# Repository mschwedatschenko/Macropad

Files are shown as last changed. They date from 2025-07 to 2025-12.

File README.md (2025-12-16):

# 3x3 Macropad Custom PCB 
This PCB was designed in KiCad and programmed in Arduino IDE using C++. I used OSHPark as my manufacturer of choice, and got some beautiful purple PCBs with ENIG surface finish. The Macropad acts as a HID, with each key representing a number 1-9. These keys can be programmed to be anything the user wants.

## Pictures

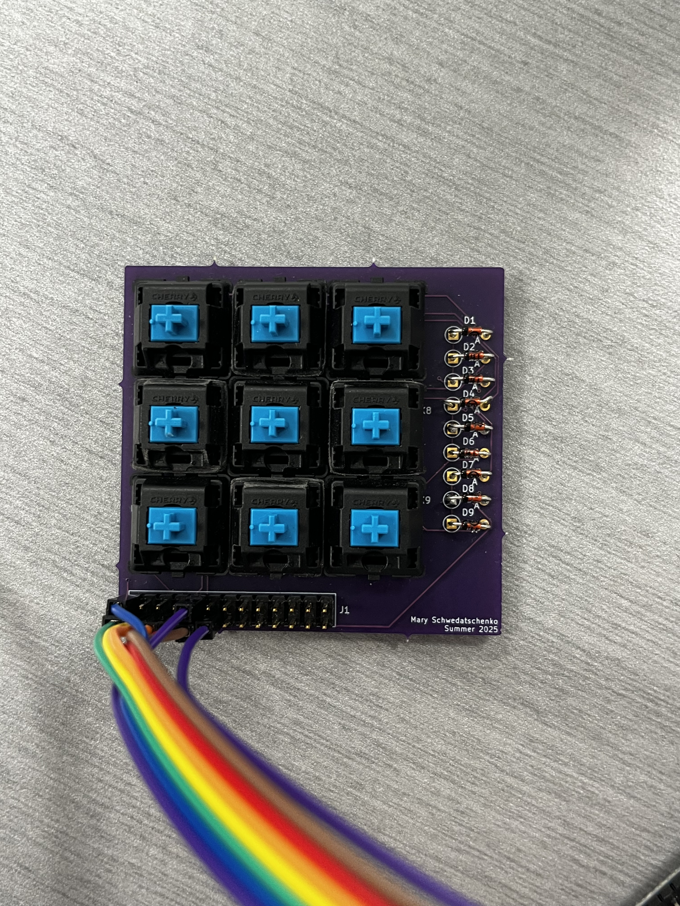
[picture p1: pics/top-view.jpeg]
board image


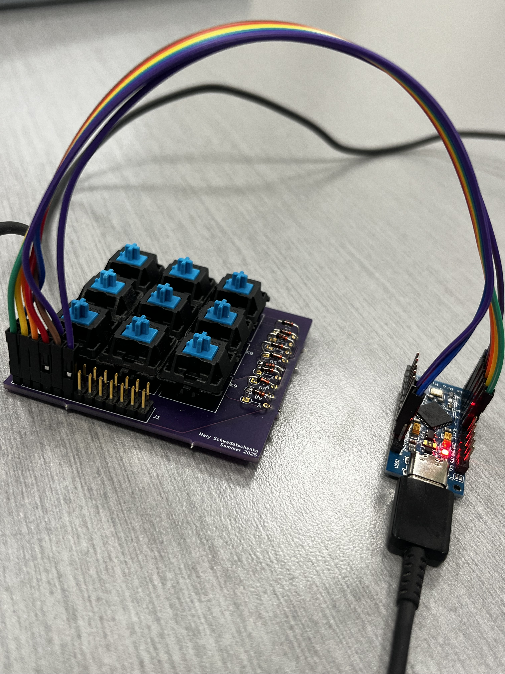
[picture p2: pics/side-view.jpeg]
board side


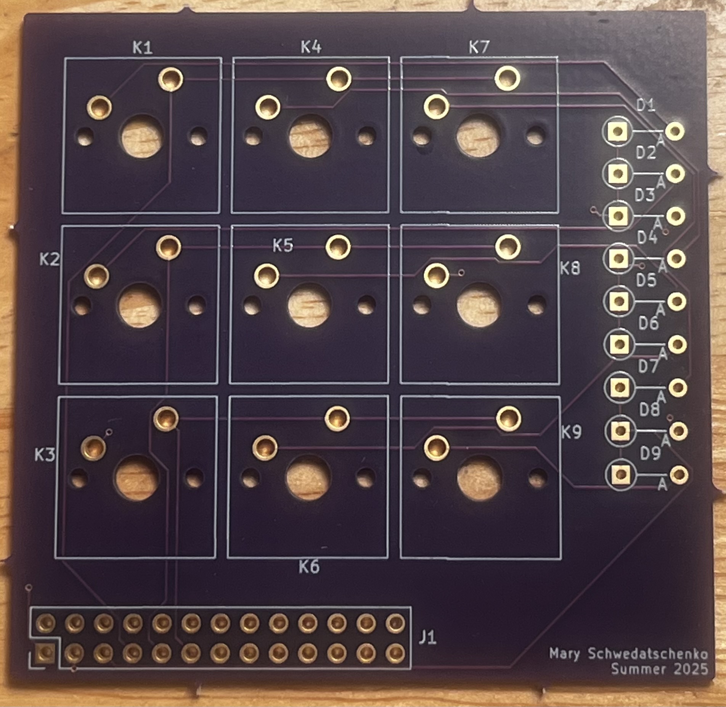
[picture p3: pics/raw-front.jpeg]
raw board front


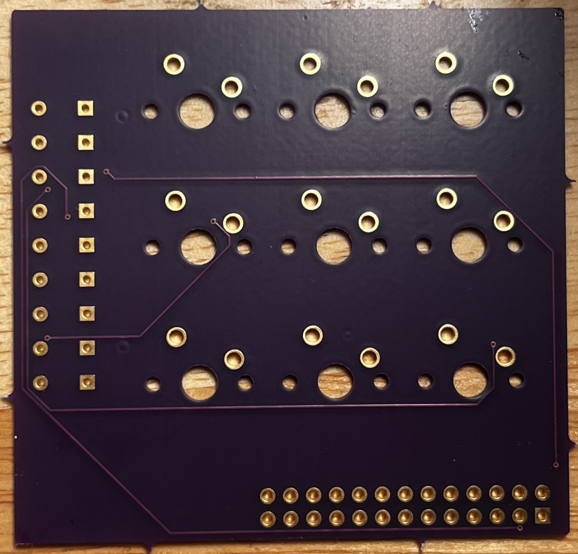
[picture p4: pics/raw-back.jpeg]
raw board back


Here's the schematic of my design:

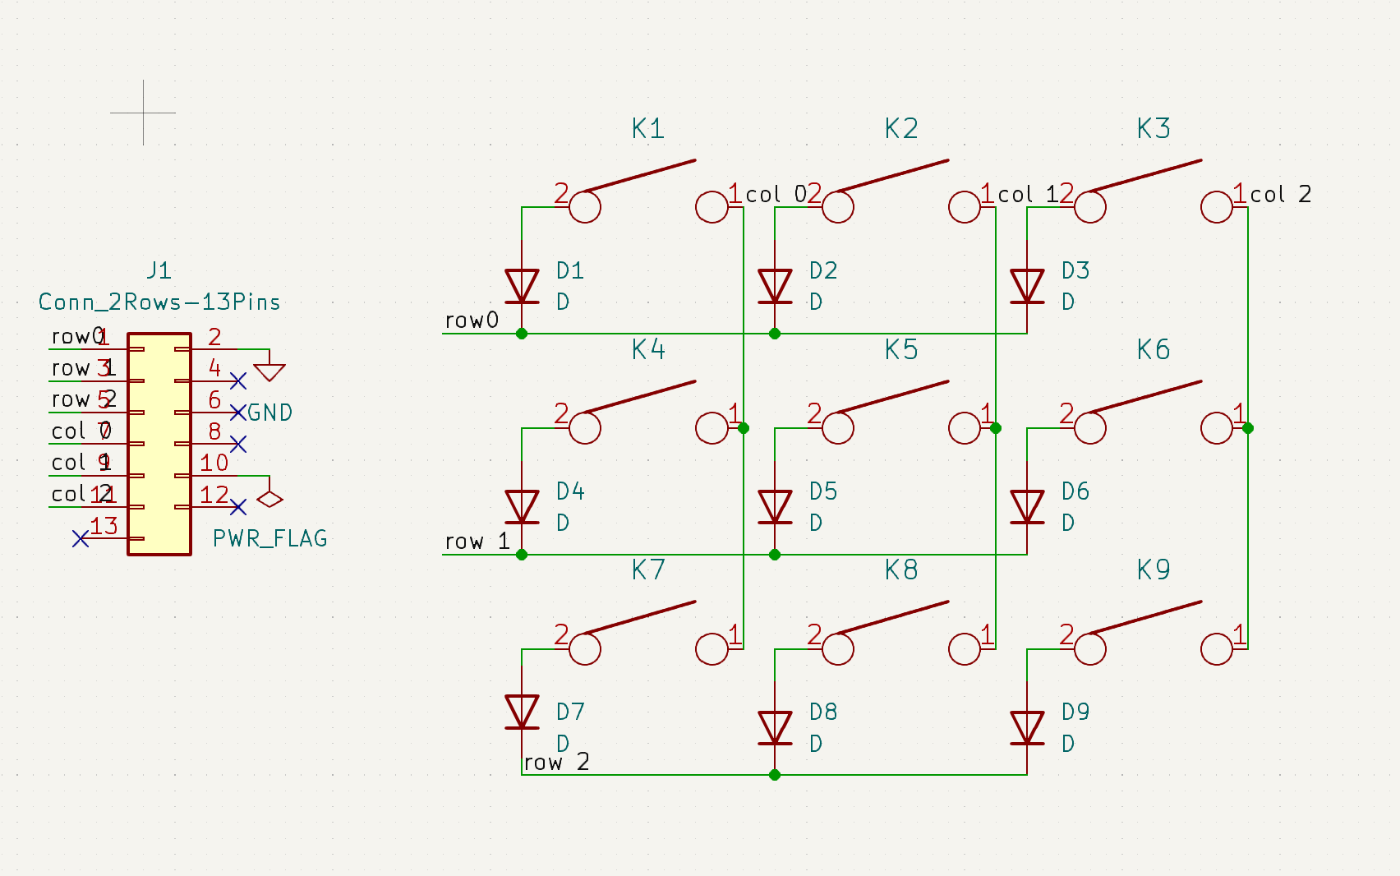
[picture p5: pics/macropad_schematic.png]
schematic


Here's the PCB layout of my design:

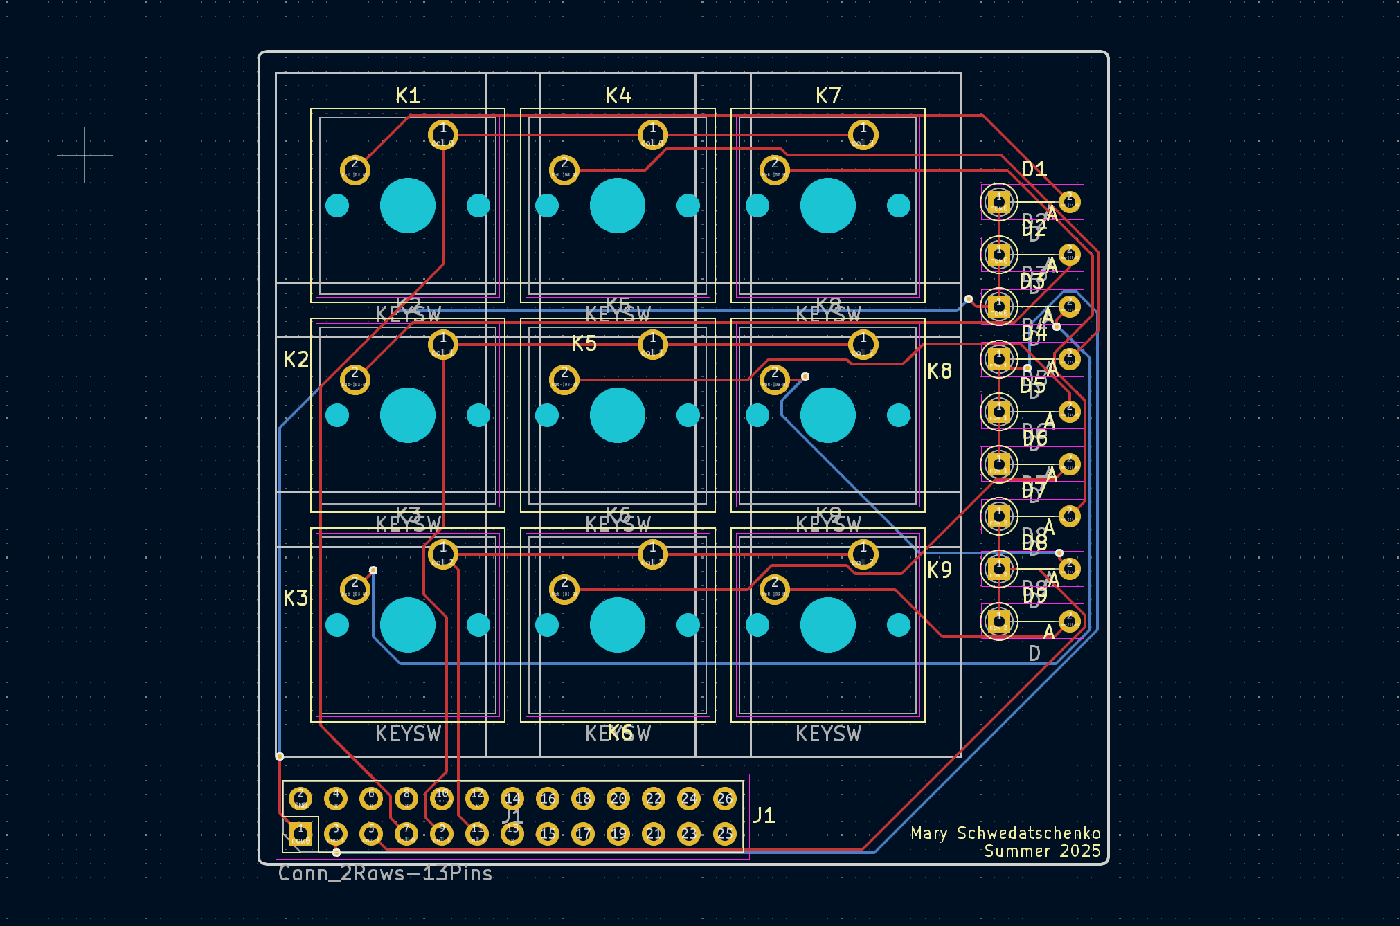
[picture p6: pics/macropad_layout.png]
layout


## Notes
I made the switch footprints far too close to one another, so I had to sand down the switches in order for them to be soldered correctly. This design does not support keycaps. Additionally, future iterations should include the Arduino Micro on the board itself, as it is a pain to have the Arduino Micro hanging off.

I'm currently in the process of making a 60% Keyboard PCB. 

## Purpose
After losing access to my mechanical keyboard I used for a while and just relying on my laptop's built-in keyboard, I had the desire to make my own mechanical keyboard completely from scratch. This macropad serves as a precursor to a 60% keyboard I hope to create during this academic year using a bare ATMega32U4 Microcontroller rather than an Arduino Micro, and to test the waters with the project on a smaller scale. 

It made sense to stick with the Arduino Micro for the microcontroller for this project since I will be strictly using through-hole soldering. With the 60% project, having regular access to WPI's reflow oven will yield hopefully better results using SMT soldering (hand soldering all of the pins on the microcontroller sounds like a nightmare).

I hope to make the switches on the 60% keyboard hot-swappable. I used Cherry MX switches for this macropad and soldered them directly to the PCB.

## BOM
Arduino Micro (alternative knockoff linked here)
https://www.amazon.com/dp/B0B6HYLC44?ref=ppx_yo2ov_dt_b_fed_asin_title 

9x THT Diodes
https://www.digikey.com/en/products/detail/onsemi/1N4148/458603 

9x Cherry MX Switches
https://www.digikey.com/en/products/detail/cherry-americas-llc/MX1A-E1NW/20180

1x 2x12 Pin Header
https://www.mouser.com/ProductDetail/Amphenol-FCI/67996-126HLF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 

Female to Female Jumper Wires
https://www.amazon.com/California-JOS-Breadboard-Optional-Multicolored/dp/B0BRTKTV64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

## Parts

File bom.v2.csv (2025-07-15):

Reference | Value | Datasheet | Footprint | Qty | DNP
D1,D2,D3,D4,D5,D6,D7,D8,D9 | D | ~ | Diode_THT:D_DO-35_SOD27_P5.08mm_Vertical_AnodeUp | 9
J1 | Conn_2Rows-13Pins | ~ | Connector_PinHeader_2.54mm:PinHeader_2x13_P2.54mm_Vertical | 1
K1,K2,K3,K4,K5,K6,K7,K8,K9 | KEYSW |  | Button_Switch_Keyboard:SW_Cherry_MX_1.00u_PCB | 9

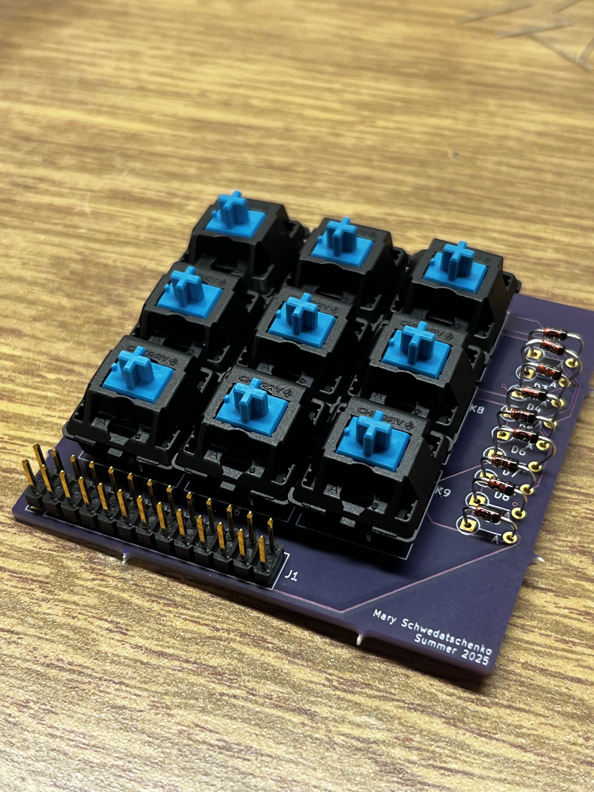
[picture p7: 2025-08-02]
pics/components.jpeg

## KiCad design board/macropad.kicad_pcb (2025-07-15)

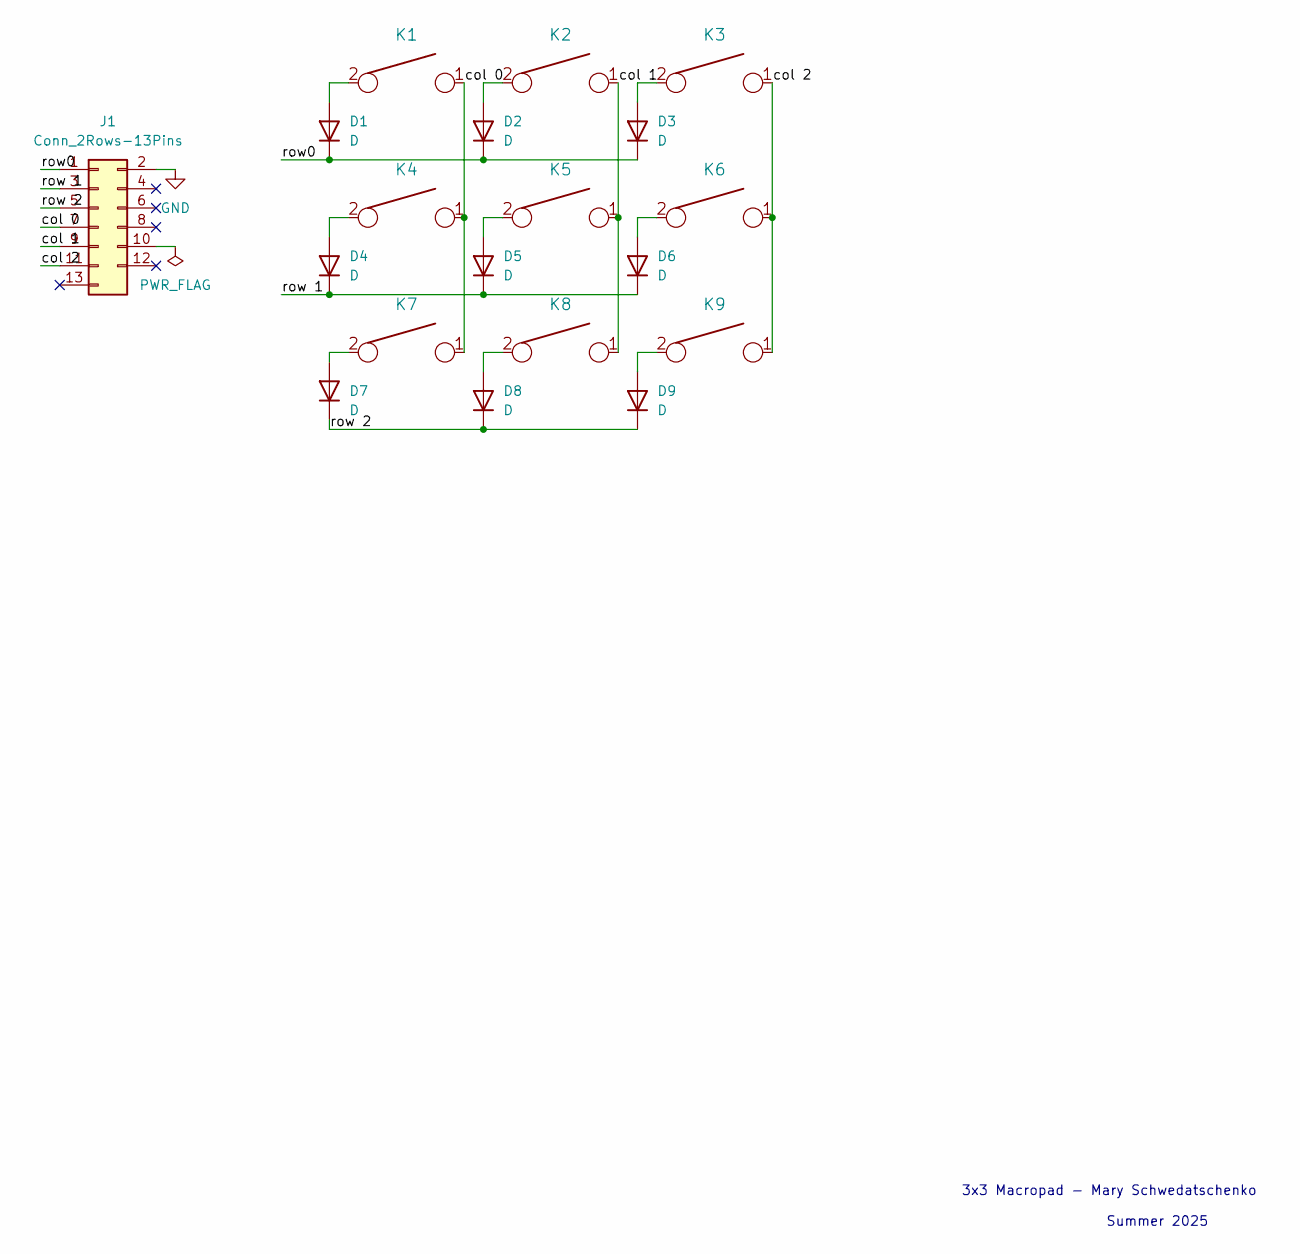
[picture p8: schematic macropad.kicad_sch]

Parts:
D1, D2, D3, D4, D5, D6, D7, D8, D9: D; D_DO-35_SOD27_P5.08mm_Vertical_AnodeUp
J1: Conn_2Rows-13Pins; PinHeader_2x13_P2.54mm_Vertical
K1, K2, K3, K4, K5, K6, K7, K8, K9: KEYSW; SW_Cherry_MX_1.00u_PCB

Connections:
/col 0: J1.7, K1.1, K4.1, K7.1
/col 1: J1.9, K2.1, K5.1, K8.1
/col 2: J1.11, K3.1, K6.1, K9.1
/row0: D1.1 (K), D2.1 (K), D3.1 (K), J1.1
/row 1: D4.1 (K), D5.1 (K), D6.1 (K), J1.3
/row 2: D7.1 (K), D8.1 (K), D9.1 (K), J1.5
GND: J1.2
unnamed: D1.2 (A), K1.2
unnamed: D2.2 (A), K2.2
unnamed: D3.2 (A), K3.2
unnamed: D4.2 (A), K4.2
unnamed: D5.2 (A), K5.2
unnamed: D6.2 (A), K6.2
unnamed: D7.2 (A), K7.2
unnamed: D8.2 (A), K8.2
unnamed: D9.2 (A), K9.2

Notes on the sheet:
Summer 2025
3x3 Macropad - Mary Schwedatschenko

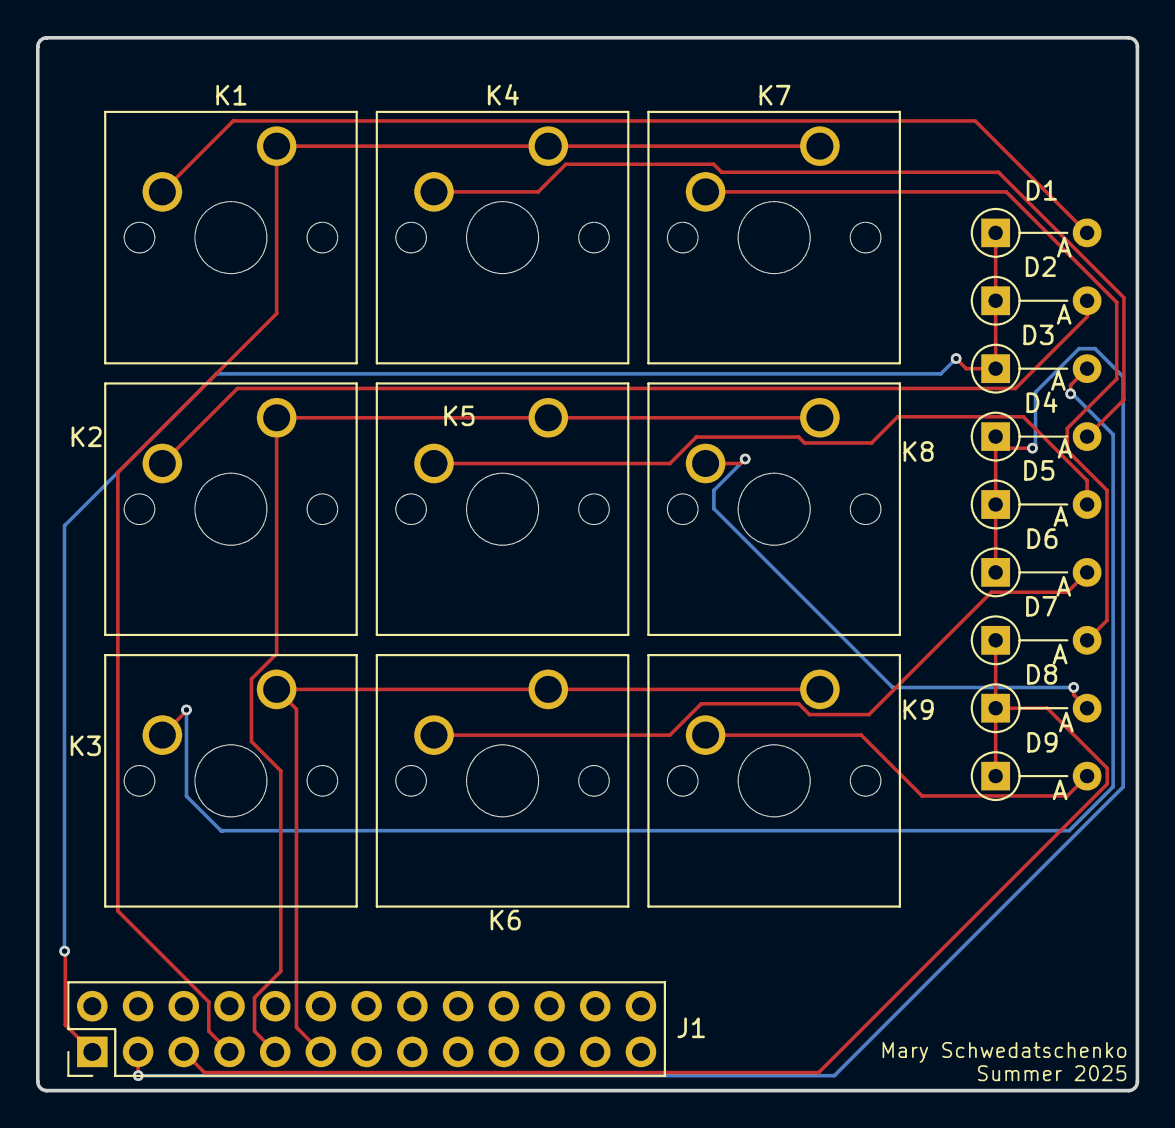
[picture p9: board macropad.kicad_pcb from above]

Board: 2 copper layers, 61.1 x 58.5 mm, 19 parts (0 on the bottom side), 15 nets.

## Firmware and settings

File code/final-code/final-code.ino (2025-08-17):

#include <Keypad.h>
#include <Keyboard.h>

const byte row = 3;
const byte col = 3;

char matrix[row][col] = {
  {'1','2','3'},
  {'4','5','6'},
  {'7','8','9'}
};

byte rowPins[row] = {6,7,9};
byte colPins[col] = {3,4,5};


Keypad keypad = Keypad(makeKeymap(matrix), rowPins, colPins, row, col);

void setup(){
  Keyboard.begin();
}

void loop(){
  char key = keypad.getKey();

  if(key){
    Keyboard.write(key);
    delay(100);
  }
}

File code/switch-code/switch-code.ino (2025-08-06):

#include "Keyboard.h"

const int buttonPin = 3;
int prevState = HIGH;

void setup() {
  pinMode(buttonPin, INPUT_PULLUP);
  Keyboard.begin();
}

void loop() {
  int buttonState = digitalRead(buttonPin);
  if(buttonState == LOW && prevState == HIGH)
  {
    Keyboard.press(97);
    delay(50);
  }

  if(buttonState == HIGH && prevState == LOW)
  {
    Keyboard.release(97);
    delay(50);
  }

  prevState = buttonState;
}

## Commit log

2025-06-16 initial: switch matrix completed i think
    [macropad.kicad_pcb, macropad.kicad_sch]
2025-06-16 added board folder
    [macropad.kicad_pcb, macropad.kicad_sch]
2025-06-17 uh oh this might wreck everything
    [macropad.kicad_pcb, macropad.kicad_sch]
2025-06-17 deleted vcc
    [macropad.kicad_sch]
2025-06-17 footprint libs assigned, look for arduino
    [BOM.csv, macropad.kicad_pcb, macropad.kicad_sch]
2025-06-18 added updated bom
    [BOM.csv, bom.v2.csv]
2025-07-13 changed symbol to pro micro from arduino micro
2025-07-13 actually untracking .lck hopefully
    [macropad.kicad_pcb]
2025-07-13 no more pro micro footprint, optimized
    [macropad.kicad_sch]
2025-07-15 forgot to save again -- actually routed
    [macropad.kicad_pcb]
2025-07-15 final tweaks... sent off for manufacturing
    [macropad.kicad_pcb]
2025-07-15 updated bom & readme
    [bom.v2.csv]
2025-07-15 added gerber files & made folders
    [macropad-B_Cu.gbl, macropad-B_Mask.gbs, macropad-B_Paste.gbp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]
2025-08-06 initial switch code for 1 switch -doesn't work
